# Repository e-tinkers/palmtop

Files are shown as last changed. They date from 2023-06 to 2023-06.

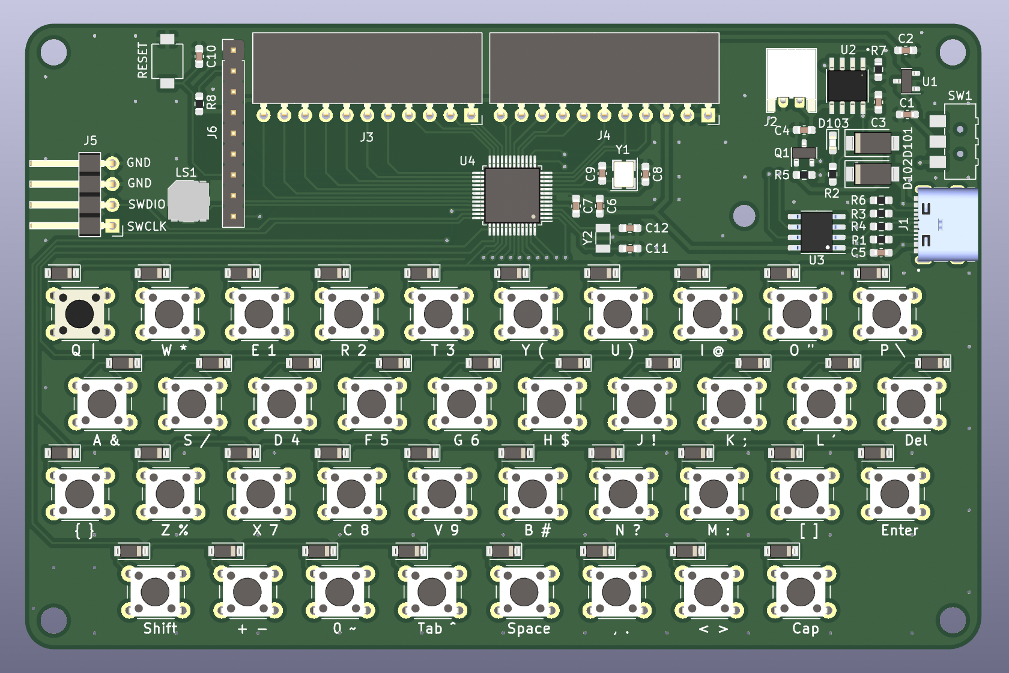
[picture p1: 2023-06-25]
bom/3D_render.png

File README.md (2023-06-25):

# PalmTop - STM32G070-based Handheld

This repository contains the Kicad schematic and PCB files, plus hardware test sketch for 
[PalmTop](https://www.e-tinkers.com/2023/06/build-a-palmtop-handheld-with-stm32g070-part-1/) project.

PalmTop - STM32G070-based handheld

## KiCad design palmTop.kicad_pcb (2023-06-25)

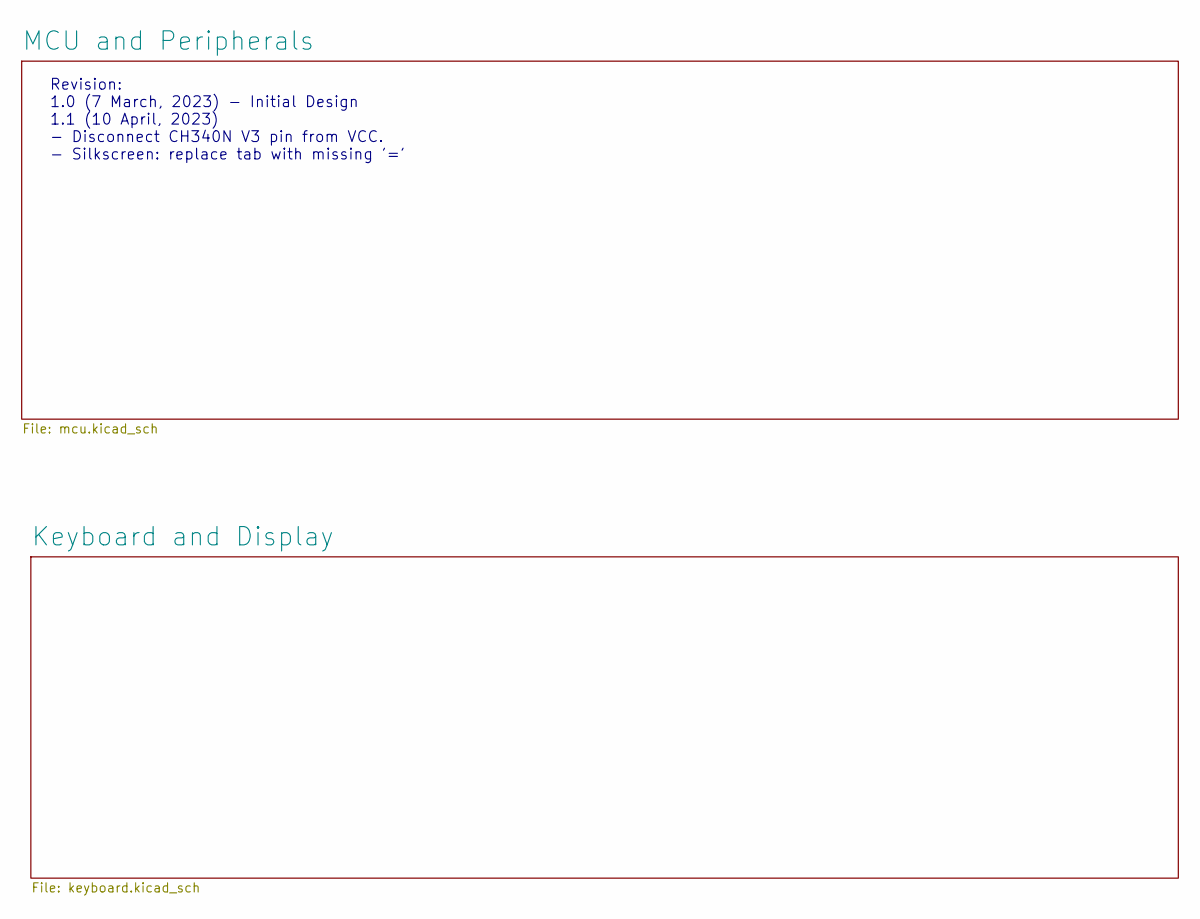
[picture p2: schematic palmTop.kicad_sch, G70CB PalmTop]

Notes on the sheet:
Revision: 1.0 (7 March, 2023) - Initial Design 1.1 (10 April, 2023) - Disconnect CH340N V3 pin from VCC. - Silkscreen: replace tab with missing '='

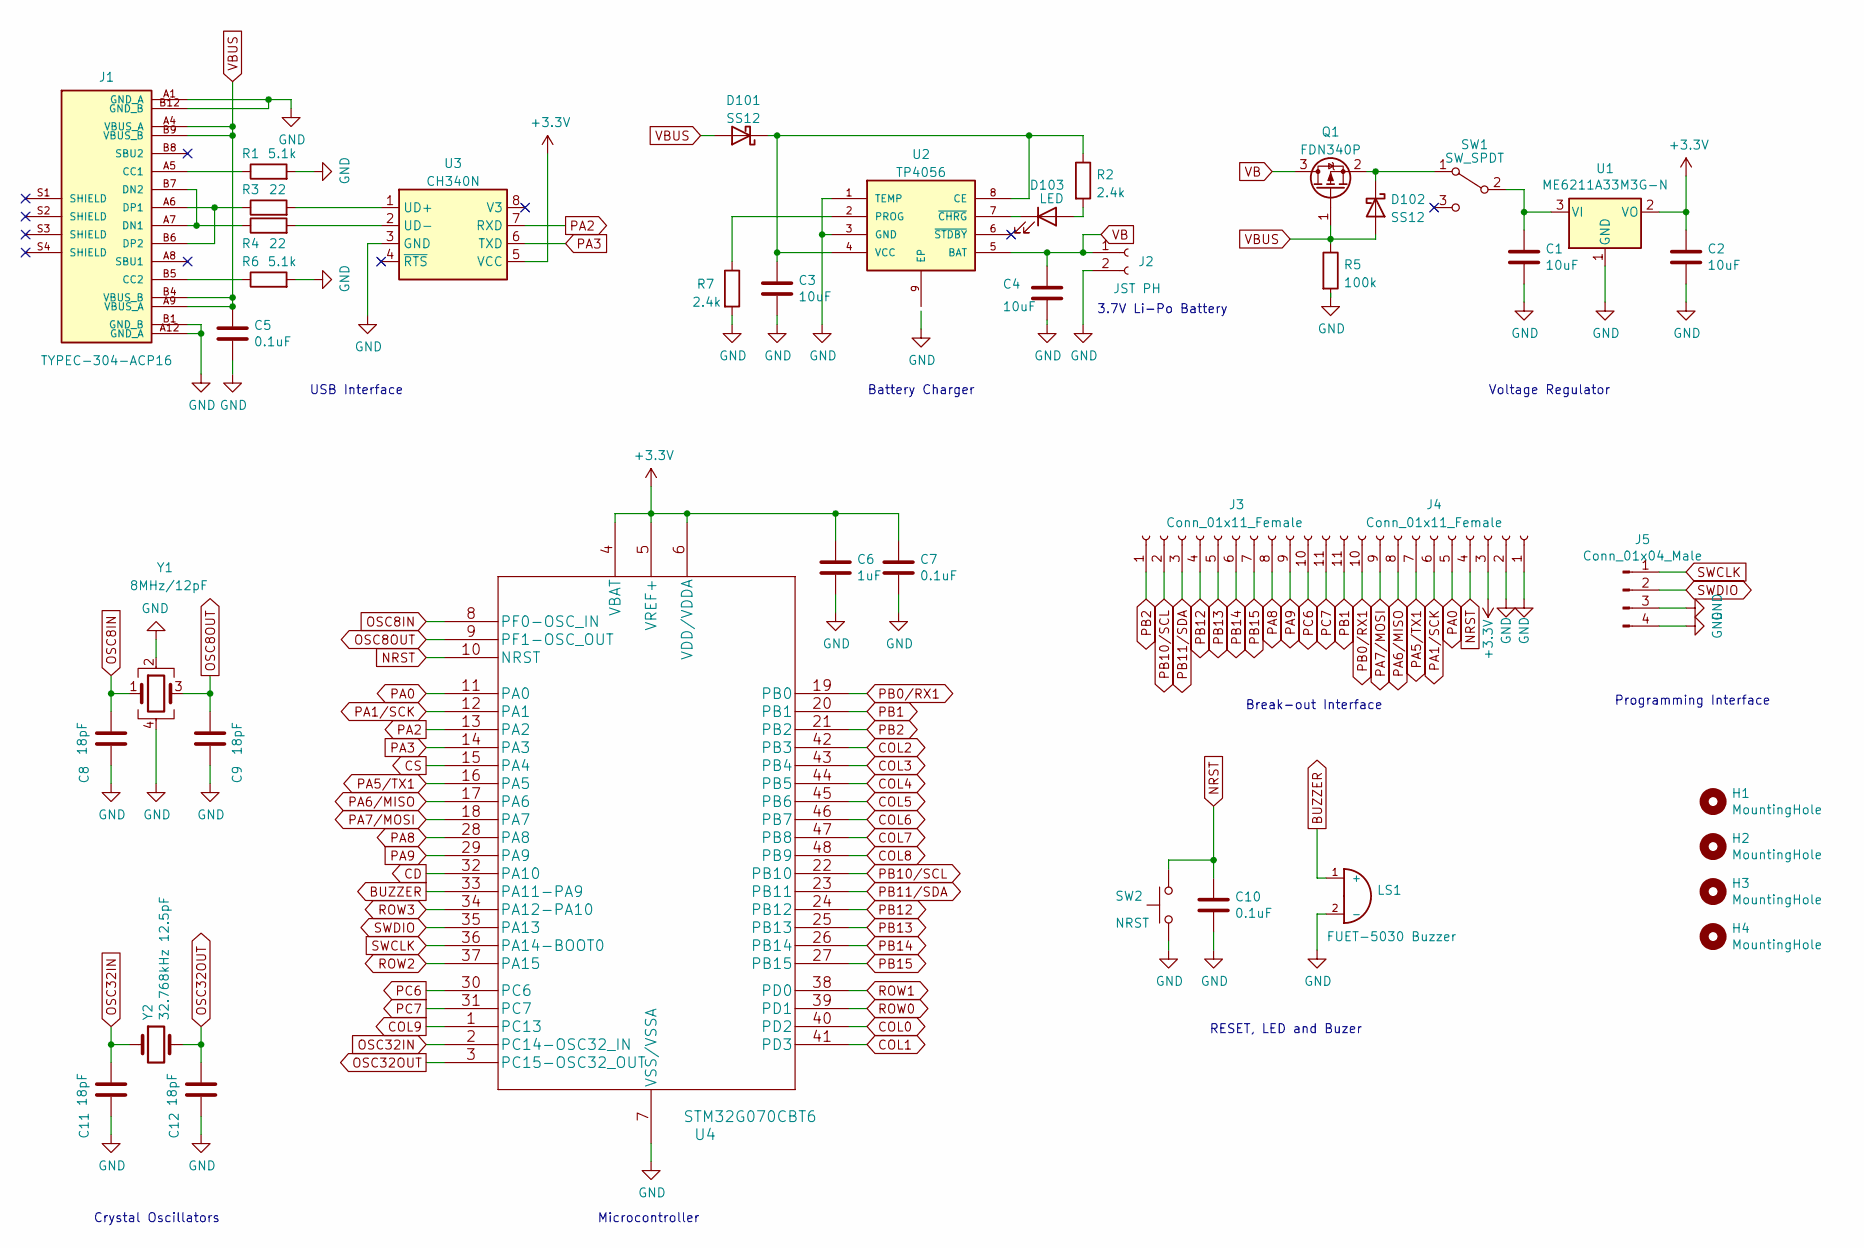
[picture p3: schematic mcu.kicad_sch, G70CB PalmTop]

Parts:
C1, C2, C3, C4: 10uF; C_0603_1608Metric_Pad1.08x0.95mm_HandSolder
C5, C7, C10: 0.1uF; C_0603_1608Metric_Pad1.08x0.95mm_HandSolder
C6: 1uF; C_0603_1608Metric_Pad1.08x0.95mm_HandSolder
C8, C9, C11, C12: 18pF; C_0603_1608Metric_Pad1.08x0.95mm_HandSolder
D101, D102: SS12; D_SMA
D103: LED; LED_0603_1608Metric_Pad1.05x0.95mm_HandSolder
H1, H2, H3, H4: MountingHole; MountingHole_3.2mm_M3
J1: TYPEC-304-ACP16; XUNPU_TYPEC-304-ACP16
J2: JST PH; JST_PH_S2B-PH-K_1x02_P2.00mm_Horizontal
J3, J4: Conn_01x11_Female; PinSocket_1x11_P2.54mm_Horizontal
J5: Conn_01x04_Male; PinHeader_1x04_P2.54mm_Horizontal
LS1: FUET-5030 Buzzer; FUET-5030-BUZZER
Q1: FDN340P; SOT-23
R1, R6: 5.1k; R_0603_1608Metric_Pad0.98x0.95mm_HandSolder
R2, R7: 2.4k; R_0603_1608Metric_Pad0.98x0.95mm_HandSolder
R3, R4: 22; R_0603_1608Metric_Pad0.98x0.95mm_HandSolder
R5: 100k; R_0603_1608Metric_Pad0.98x0.95mm_HandSolder
SW1: SW_SPDT; SW_SPDT_XKB_SK-3390A-L1
SW2: NRST; SW_TS-1185-X-X
U1: ME6211A33M3G-N; SOT-23
U2: TP4056; SOP127P600X175-9N
U3: CH340N; SOP-8_3.76x4.96mm_P1.27mm
U4: STM32G070CBT6; LQFP-48_7x7mm_P0.5mm
Y1: 8MHz/12pF; Crystal_SMD_3225-4Pin_3.2x2.5mm
Y2: 32.768kHz 12.5pF; Crystal_SMD_3215-2Pin_3.2x1.5mm

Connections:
BUZZER: LS1.1 (+), U4.33 (PA11-PA9)
+3V3: C2.1, C6.1, C7.1, J4.3, U1.2 (VO), U3.5 (VCC), U4.4 (VBAT), U4.5 (VREF+), U4.6 (VDD/VDDA); also elsewhere on the board
CD: U4.32 (PA10); also elsewhere on the board
COL0: U4.40 (PD2); also elsewhere on the board
COL1: U4.41 (PD3); also elsewhere on the board
COL2: U4.42 (PB3); also elsewhere on the board
COL3: U4.43 (PB4); also elsewhere on the board
COL4: U4.44 (PB5); also elsewhere on the board
COL5: U4.45 (PB6); also elsewhere on the board
COL6: U4.46 (PB7); also elsewhere on the board
COL7: U4.47 (PB8); also elsewhere on the board
COL8: U4.48 (PB9); also elsewhere on the board
COL9: U4.1 (PC13); also elsewhere on the board
CS: U4.15 (PA4); also elsewhere on the board
GND: C1.2, C2.2, C3.2, C4.2, C5.2, C6.2, C7.2, C8.2, C9.2, C10.1, C11.2, C12.2, J1.A1 (GND_A), J1.A12 (GND_A), J1.B1 (GND_B), J1.B12 (GND_B), J2.2, J4.1, J4.2, J5.3, J5.4, LS1.2 (-), R1.2, R5.2, R6.2, R7.2, SW2.1, U1.1 (GND), U2.1 (TEMP), U2.3 (GND), U3.3 (GND), U4.7 (VSS/VSSA), Y1.2, Y1.4; also elsewhere on the board
NRST: C10.2, J4.4, SW2.2, U4.10 (NRST); also elsewhere on the board
unnamed: C1.1, SW1.2 (B), U1.3 (VI)
unnamed: C3.1, D101.1 (K), R2.1, U2.4 (VCC), U2.8 (CE)
unnamed: D102.1 (K), Q1.2 (S), SW1.1 (A)
unnamed: D103.1 (K), U2.7 (~CHRG)
unnamed: D103.2 (A), R2.2
unnamed: J1.A5 (CC1), R1.1
unnamed: J1.A6 (DP1), J1.B6 (DP2), R3.1
unnamed: J1.A7 (DN1), J1.B7 (DN2), R4.1
unnamed: J1.B5 (CC2), R6.1
unnamed: R3.2, U3.1 (UD+)
unnamed: R4.2, U3.2 (UD-)
unnamed: R7.1, U2.2 (PROG)
OSC8IN: C8.1, U4.8 (PF0-OSC_IN), Y1.1
OSC8OUT: C9.1, U4.9 (PF1-OSC_OUT), Y1.3
OSC32IN: C11.1, U4.2 (PC14-OSC32_IN), Y2.1
OSC32OUT: C12.1, U4.3 (PC15-OSC32_OUT), Y2.2
PA0: J4.5, U4.11 (PA0)
PA1/SCK: J4.6, U4.12 (PA1); also elsewhere on the board
PA2: U3.7 (RXD), U4.13 (PA2)
PA3: U3.6 (TXD), U4.14 (PA3)
PA5/TX1: J4.7, U4.16 (PA5)
PA6/MISO: J4.8, U4.17 (PA6)
PA7/MOSI: J4.9, U4.18 (PA7); also elsewhere on the board
PA8: J3.8, U4.28 (PA8)
PA9: J3.9, U4.29 (PA9)
PB0/RX1: J4.10, U4.19 (PB0)
PB1: J4.11, U4.20 (PB1)
PB2: J3.1, U4.21 (PB2)
PB10/SCL: J3.2, U4.22 (PB10)
PB11/SDA: J3.3, U4.23 (PB11)
PB12: J3.4, U4.24 (PB12)
PB13: J3.5, U4.25 (PB13)
PB14: J3.6, U4.26 (PB14)
PB15: J3.7, U4.27 (PB15)
PC6: J3.10, U4.30 (PC6)
PC7: J3.11, U4.31 (PC7)
ROW0: U4.39 (PD1); also elsewhere on the board
ROW1: U4.38 (PD0); also elsewhere on the board
ROW2: U4.37 (PA15); also elsewhere on the board
ROW3: U4.34 (PA12-PA10); also elsewhere on the board
SWCLK: J5.1, U4.36 (PA14-BOOT0)
SWDIO: J5.2, U4.35 (PA13)
VB: C4.1, J2.1, Q1.3 (D), U2.5 (BAT)
VBUS: C5.1, D101.2 (A), D102.2 (A), J1.A4 (VBUS_A), J1.A9 (VBUS_A), J1.B4 (VBUS_B), J1.B9 (VBUS_B), Q1.1 (G), R5.1

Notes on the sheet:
RESET, LED and Buzer
Battery Charger
Microcontroller
USB Interface
Voltage Regulator
3.7V Li-Po Battery
Crystal Oscillators
Programming Interface
Break-out Interface

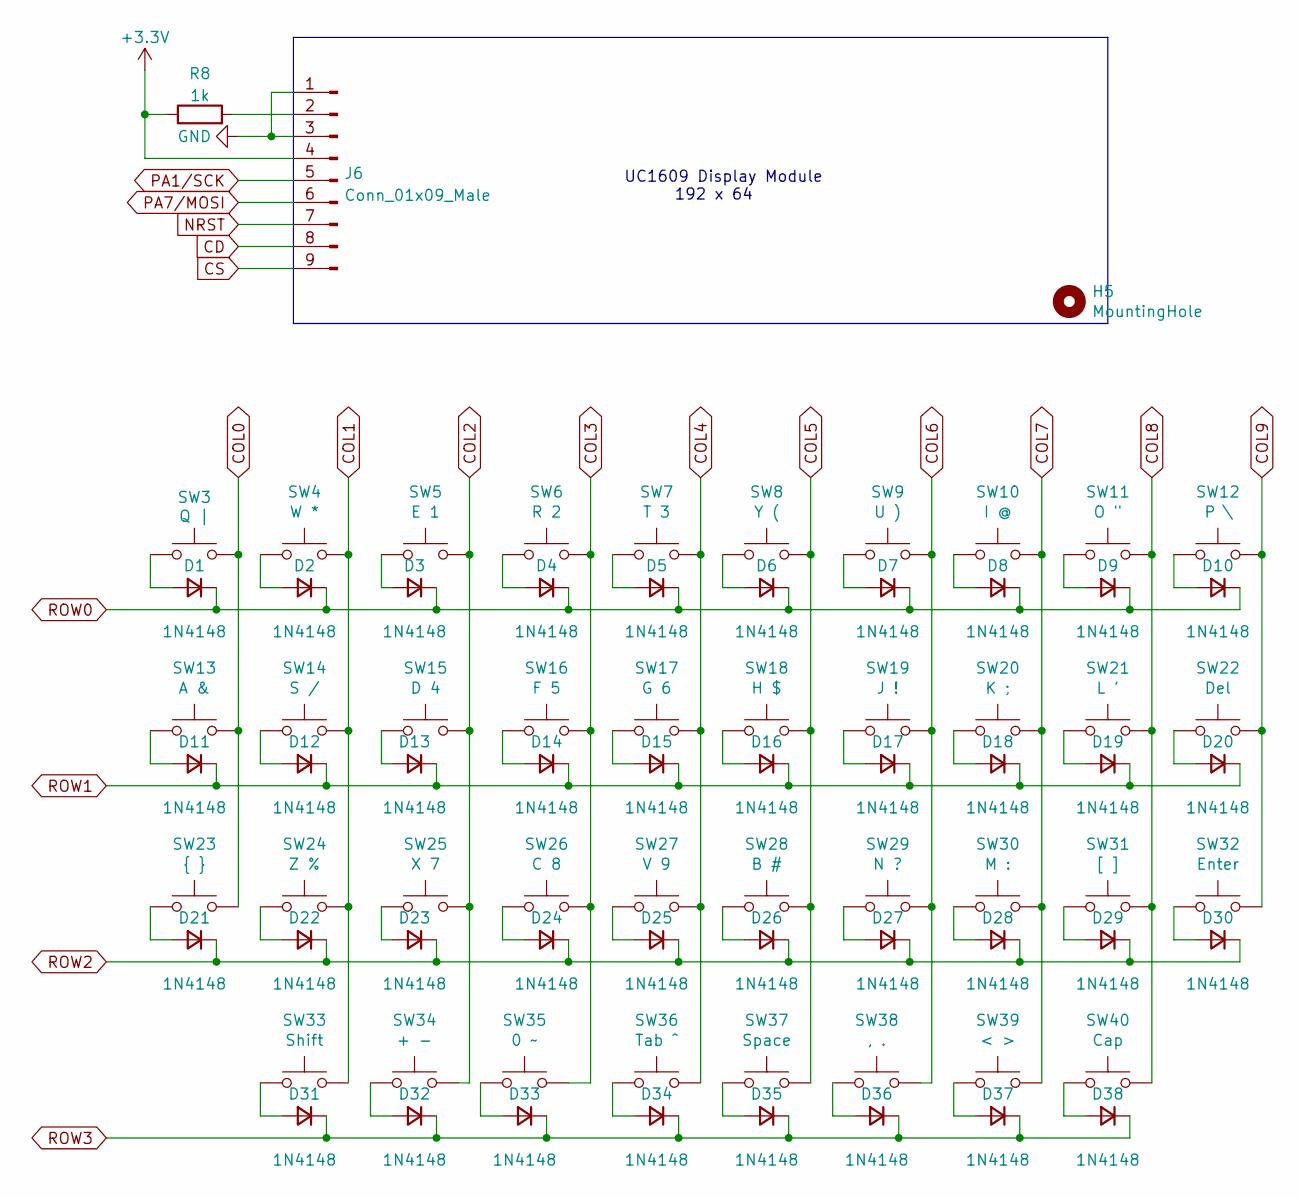
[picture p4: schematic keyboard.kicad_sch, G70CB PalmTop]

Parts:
D1, D2, D3, D4, D5, D6, D7, D8, D9, D10, D11, D12, D13, D14, D15, D16, D17, D18, D19, D20, D21, D22, D23, D24, D25, D26, D27, D28, D29, D30, D31, D32, D33, D34, D35, D36, D37, D38: 1N4148; D_SOD-123
H5: MountingHole; MountingHole_2.7mm_M2.5
J6: Conn_01x09_Male; PinHeader_1x09_P2.54mm_Vertical
R8: 1k; R_0603_1608Metric_Pad0.98x0.95mm_HandSolder
SW3: Q |; SW_PUSH_6mm_XKB_TC-1102-X-X-X
SW4: W *; SW_PUSH_6mm_XKB_TC-1102-X-X-X
SW5: E 1; SW_PUSH_6mm_XKB_TC-1102-X-X-X
SW6: R 2; SW_PUSH_6mm_XKB_TC-1102-X-X-X
SW7: T 3; SW_PUSH_6mm_XKB_TC-1102-X-X-X
SW8: Y (; SW_PUSH_6mm_XKB_TC-1102-X-X-X
SW9: U ); SW_PUSH_6mm_XKB_TC-1102-X-X-X
SW10: I @; SW_PUSH_6mm_XKB_TC-1102-X-X-X
SW11: O "; SW_PUSH_6mm_XKB_TC-1102-X-X-X
SW12: P \; SW_PUSH_6mm_XKB_TC-1102-X-X-X
SW13: A &; SW_PUSH_6mm_XKB_TC-1102-X-X-X
SW14: S /; SW_PUSH_6mm_XKB_TC-1102-X-X-X
SW15: D 4; SW_PUSH_6mm_XKB_TC-1102-X-X-X
SW16: F 5; SW_PUSH_6mm_XKB_TC-1102-X-X-X
SW17: G 6; SW_PUSH_6mm_XKB_TC-1102-X-X-X
SW18: H $; SW_PUSH_6mm_XKB_TC-1102-X-X-X
SW19: J !; SW_PUSH_6mm_XKB_TC-1102-X-X-X
SW20: K ;; SW_PUSH_6mm_XKB_TC-1102-X-X-X
SW21: L '; SW_PUSH_6mm_XKB_TC-1102-X-X-X
SW22: Del; SW_PUSH_6mm_XKB_TC-1102-X-X-X
SW23: { }; SW_PUSH_6mm_XKB_TC-1102-X-X-X
SW24: Z %; SW_PUSH_6mm_XKB_TC-1102-X-X-X
SW25: X 7; SW_PUSH_6mm_XKB_TC-1102-X-X-X
SW26: C 8; SW_PUSH_6mm_XKB_TC-1102-X-X-X
SW27: V 9; SW_PUSH_6mm_XKB_TC-1102-X-X-X
SW28: B #; SW_PUSH_6mm_XKB_TC-1102-X-X-X
SW29: N ?; SW_PUSH_6mm_XKB_TC-1102-X-X-X
SW30: M :; SW_PUSH_6mm_XKB_TC-1102-X-X-X
SW31: [ ]; SW_PUSH_6mm_XKB_TC-1102-X-X-X
SW32: Enter; SW_PUSH_6mm_XKB_TC-1102-X-X-X
SW33: Shift; SW_PUSH_6mm_XKB_TC-1102-X-X-X
SW34: + -; SW_PUSH_6mm_XKB_TC-1102-X-X-X
SW35: 0 ~; SW_PUSH_6mm_XKB_TC-1102-X-X-X
SW36: Tab ^; SW_PUSH_6mm_XKB_TC-1102-X-X-X
SW37: Space; SW_PUSH_6mm_XKB_TC-1102-X-X-X
SW38: , .; SW_PUSH_6mm_XKB_TC-1102-X-X-X
SW39: < >; SW_PUSH_6mm_XKB_TC-1102-X-X-X
SW40: Cap; SW_PUSH_6mm_XKB_TC-1102-X-X-X

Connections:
+3V3: J6.4, R8.1; also elsewhere on the board
CD: J6.8; also elsewhere on the board
COL0: SW3.2, SW13.2, SW23.2; also elsewhere on the board
COL1: SW4.2, SW14.2, SW24.2, SW33.2; also elsewhere on the board
COL2: SW5.2, SW15.2, SW25.2, SW34.2; also elsewhere on the board
COL3: SW6.2, SW16.2, SW26.2, SW35.2; also elsewhere on the board
COL4: SW7.2, SW17.2, SW27.2, SW36.2; also elsewhere on the board
COL5: SW8.2, SW18.2, SW28.2, SW37.2; also elsewhere on the board
COL6: SW9.2, SW19.2, SW29.2, SW38.2; also elsewhere on the board
COL7: SW10.2, SW20.2, SW30.2, SW39.2; also elsewhere on the board
COL8: SW11.2, SW21.2, SW31.2, SW40.2; also elsewhere on the board
COL9: SW12.2, SW22.2, SW32.2; also elsewhere on the board
CS: J6.9; also elsewhere on the board
GND: J6.1, J6.3; also elsewhere on the board
NRST: J6.7; also elsewhere on the board
unnamed: D1.2 (A), SW3.1
unnamed: D2.2 (A), SW4.1
unnamed: D3.2 (A), SW5.1
unnamed: D4.2 (A), SW6.1
unnamed: D5.2 (A), SW7.1
unnamed: D6.2 (A), SW8.1
unnamed: D7.2 (A), SW9.1
unnamed: D8.2 (A), SW10.1
unnamed: D9.2 (A), SW11.1
unnamed: D10.2 (A), SW12.1
unnamed: D11.2 (A), SW13.1
unnamed: D12.2 (A), SW14.1
unnamed: D13.2 (A), SW15.1
unnamed: D14.2 (A), SW16.1
unnamed: D15.2 (A), SW17.1
unnamed: D16.2 (A), SW18.1
unnamed: D17.2 (A), SW19.1
unnamed: D18.2 (A), SW20.1
unnamed: D19.2 (A), SW21.1
unnamed: D20.2 (A), SW22.1
unnamed: D21.2 (A), SW23.1
unnamed: D22.2 (A), SW24.1
unnamed: D23.2 (A), SW25.1
unnamed: D24.2 (A), SW26.1
unnamed: D25.2 (A), SW27.1
unnamed: D26.2 (A), SW28.1
unnamed: D27.2 (A), SW29.1
unnamed: D28.2 (A), SW30.1
unnamed: D29.2 (A), SW31.1
unnamed: D30.2 (A), SW32.1
unnamed: D31.2 (A), SW33.1
unnamed: D32.2 (A), SW34.1
unnamed: D33.2 (A), SW35.1
unnamed: D34.2 (A), SW36.1
unnamed: D35.2 (A), SW37.1
unnamed: D36.2 (A), SW38.1
unnamed: D37.2 (A), SW39.1
unnamed: D38.2 (A), SW40.1
unnamed: J6.2, R8.2
PA1/SCK: J6.5; also elsewhere on the board
PA7/MOSI: J6.6; also elsewhere on the board
ROW0: D1.1 (K), D2.1 (K), D3.1 (K), D4.1 (K), D5.1 (K), D6.1 (K), D7.1 (K), D8.1 (K), D9.1 (K), D10.1 (K); also elsewhere on the board
ROW1: D11.1 (K), D12.1 (K), D13.1 (K), D14.1 (K), D15.1 (K), D16.1 (K), D17.1 (K), D18.1 (K), D19.1 (K), D20.1 (K); also elsewhere on the board
ROW2: D21.1 (K), D22.1 (K), D23.1 (K), D24.1 (K), D25.1 (K), D26.1 (K), D27.1 (K), D28.1 (K), D29.1 (K), D30.1 (K); also elsewhere on the board
ROW3: D31.1 (K), D32.1 (K), D33.1 (K), D34.1 (K), D35.1 (K), D36.1 (K), D37.1 (K), D38.1 (K); also elsewhere on the board

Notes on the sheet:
UC1609 Display Module 192 x 64

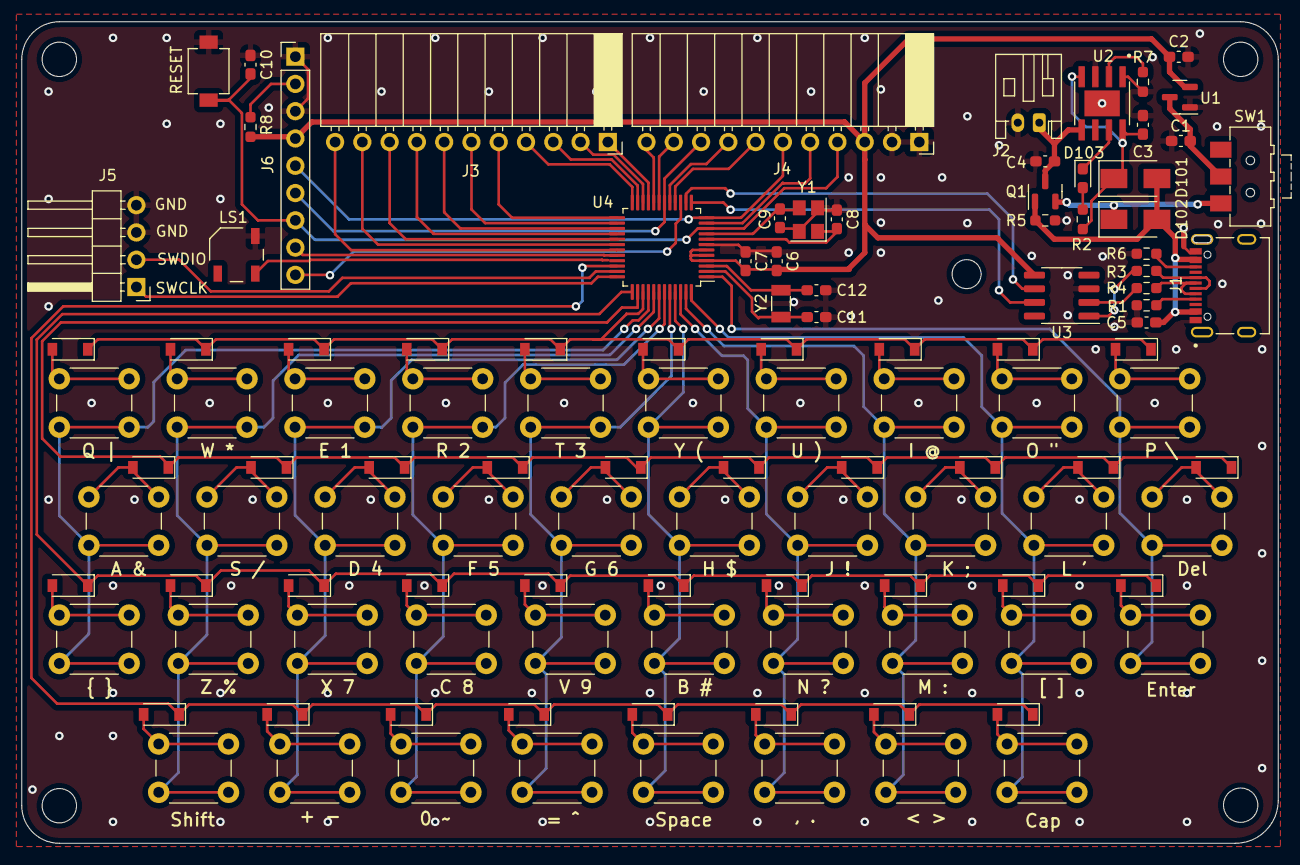
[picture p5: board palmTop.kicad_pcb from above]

Board: 2 copper layers, 117.0 x 76.5 mm, 120 parts (0 on the bottom side), 99 nets.

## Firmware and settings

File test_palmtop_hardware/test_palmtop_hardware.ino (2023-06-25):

/* 
 *  PalmTop - A STM32G070-based Development Board with keyboard, display and a BASIC interpreter
 *  
 *  The pin definitions using in this code is the hardware design of PalmTop board. It requires
 *  a custom board configuration based on stm32duino Arduino_Core_STM32 for PalmTop.
*/

#include <UC1609.h>
#include "image.h"
#include "kbd.h"


// UC1609 display settings
#define CD       PA10
#define CS       PA4
#define RST      -1    // share with MCU's NRST pin

#define CONTRAST 0x38

UC1609 lcd(CS, CD, RST);
Keyboard keyboard;


void startUpScreen() {
  lcd.drawImage(0, 0, 192, 64, logo);
  tone(BUZZER, 4000, 500);
  delay(2000);
  lcd.clearDisplay();
}

void setup() {

  pinMode(BUZZER, OUTPUT);

  keyboard.begin();

  delay(3);     // for LCD to get ready after powering up
  lcd.begin(CONTRAST);
  lcd.setFont(font5x7_extended);

  startUpScreen();

}

void loop() {

  if (keyboard.available()) {
    char c = keyboard.read();
    lcd.write(c);
  }

  delay(1);

}

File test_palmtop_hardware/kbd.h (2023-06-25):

#ifndef _KBD_H_
#define _KBD_H_
/*
 *  The Keyboard is a full function keyboard inspired by Palm Treo650 keyboard.
 *  The keyboard matrix code is based on the original work by Mark Stanley and Alexander Brevig
 *  from http://playground.arduino.cc/Code/Keypad.
 *  
 */
#include <Arduino.h>

#define NAK  0x0   // Not a key
#define SO   0xE   // For representing CapLock key
#define SI   0xF   // For representing Shift key

#define ROWS 4
#define COLS 10

#define BUZZER   PA11

enum {NORMAL, SHIFTED, CAPLOCK};

#define DEBOUNCED_INTERVAL 150

class Keyboard
{
public:

  void begin(void);
  char available();
  char read();

private:

  // GPIO Pins for keyboard matrix
  const uint8_t rowPins[ROWS] = {PD1, PD0, PA15, PA12};  // Row0 - Row3
  const uint8_t colPins[COLS] = {PD2, PD3, PB3, PB4, PB5, PB6, PB7, PB8, PB9, PC13}; //Col0 - Col9

  // Keyboard character map
  const char keys[ROWS][COLS] = {
    // Without Shift
    {'q', 'w', 'e', 'r', 't', 'y', 'u', 'i', 'o', 'p'},
    {'a', 's', 'd', 'f', 'g', 'h', 'j', 'k', 'l', '\b'},
    {'{', 'z', 'x', 'c', 'v', 'b', 'n', 'm', '[', '\n'},
    {NAK,  SI, '+', '~', '=',' ', ',', '<', SO, NAK}
  };
  const char keysShifted[4][10] = {
    // With shift
    {'|', '*', '1', '2', '3', '(', ')', '@', '\"', '\\'},
    {'&', '/', '4', '5', '6', '$', '!', ';', '\'', '\b'},
    {'}', '%', '7', '8', '9', '#', '?', ':', ']', '\n'},
    {NAK, SI, '-', '0', '^', ' ', '.', '>', SO, NAK}
  };

  uint8_t _keyState{NORMAL};
  char _keyCode{0};
};

#endif

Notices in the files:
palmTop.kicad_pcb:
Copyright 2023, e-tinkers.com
